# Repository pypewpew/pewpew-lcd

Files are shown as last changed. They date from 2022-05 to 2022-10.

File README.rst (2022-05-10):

PewPew LCD
**********

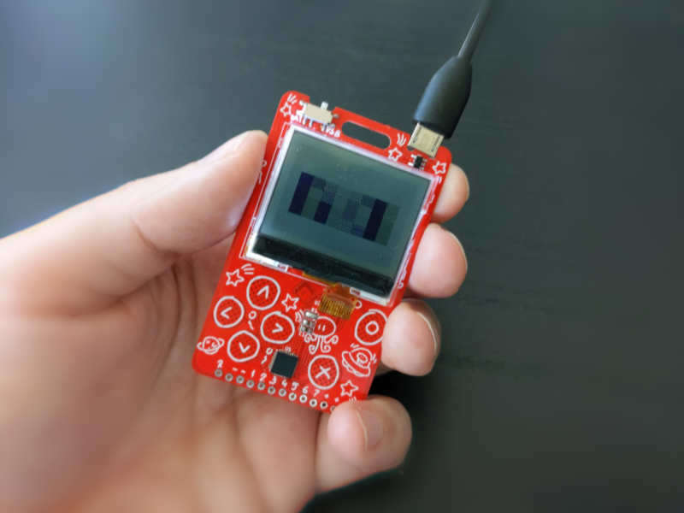
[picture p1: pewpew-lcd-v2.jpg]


PewPew LCD is a handheld gaming device designed for use in programming
workshops. Because it runs CircuitPython, you don't have to install anything on
your computer to program it: you just edit a text file on the USB drive that
appears when you connect the device.

There is a whole family of compatible PewPew devices, and PewPew LCD is just
one of them. It's distinguished by the use of a low-power monochrome LCD
display for the screen — which makes it cheap, battery-efficient, and lets you
see the error messages from your code on the screen,  without having to use any
special programs to connect to the serial console.

More information about the PewPew family is available at: https://pewpew.rtfd.io

Hardware
========

In this repository you will find the schematic, the bill of materials, the
design files and the generated gerber and pnp files, for building PewPew LCD.
You can either assemble it yourself, or use a fabrication service to do it
for you.

Software
========

For the device to function properly, it has to be loaded with proper software.
To do that, you will need a CMSIS/DAP-compatible programmer to flash the
bootloader on the microcontroller, and then you will need CircuitPython
firmware for this device, which can be flashed over USB once the bootloader is
in place. It's also convenient to put a menu program for selecting the game to
play on the device as main.py.

This device uses the same bootloader as fluff_m0. Both compiled binaries and
source code for that bootloader can be obtained from: https://github.com/adafruit/uf2-samdx1/releases/

In order to flash the bootloader, the programmer needs to be connected to the
expansion port at the bottom of the device, to pins marked as "-" for GND, "1"
for SWC, "2" for SWD, and + for 3.3V. Unless the programmer provides its own
power, the USB cable also needs to be connected, and the power switch switched
to the "USB" position. The bootloader binary needs to be flashed at address 0.

Once the bootloader is in place, a UF2 file with CircuitPython can be obtained
from the https://circuitpython.org website, or compiled from source code as per
CircuitPython's building instructions. Then the file can be copied to the
device over USB. The code for the board definition is available at 
https://github.com/adafruit/circuitpython/pull/6331

Once the firmware is in place, the menu program and any other programs desired
can be simply copied onto the device over USB.

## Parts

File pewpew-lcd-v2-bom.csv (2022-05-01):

U1 | ATSAMD21E18A-MU | 1 | mcu
U2 | AP2112K-3.3TRG1 | 1 | ldo
U3 | RH-112 | 1 | display
C1,C2 | 10uF 0805 3V | 2 | capacitor
R1 | 100ohm 0805 | 1 | resistor
X1 | MK12C02 | 1 | switch

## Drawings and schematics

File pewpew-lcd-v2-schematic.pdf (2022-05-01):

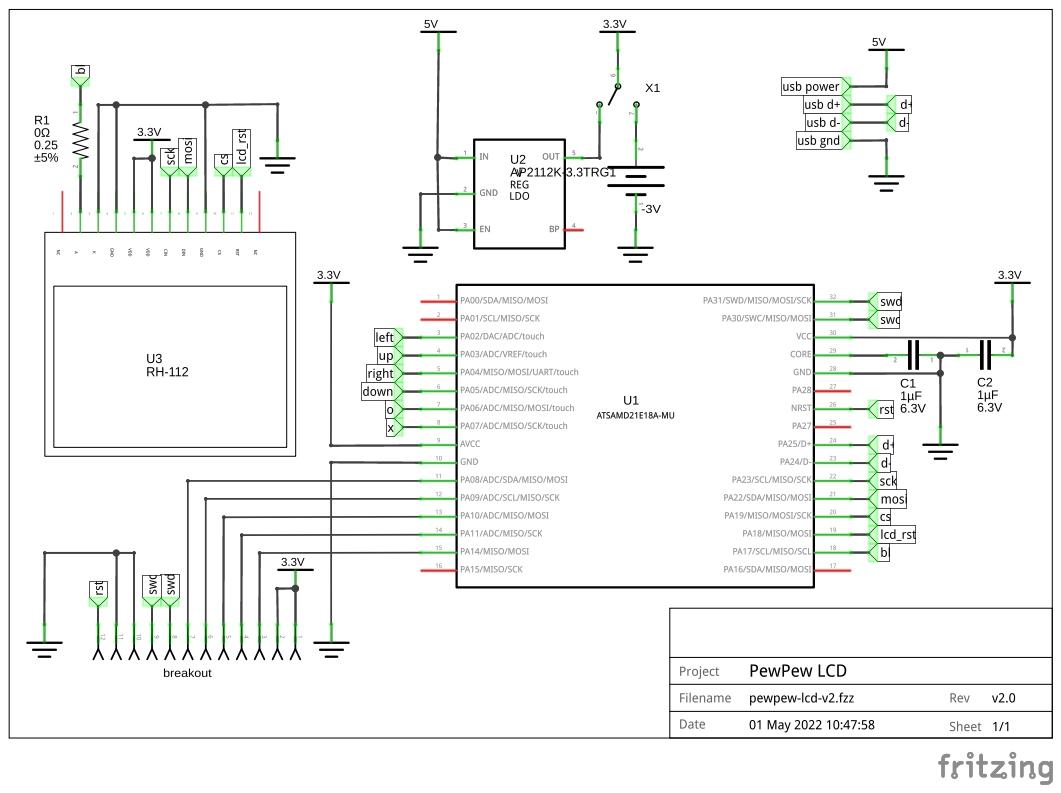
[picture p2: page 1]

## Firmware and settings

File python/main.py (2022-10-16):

import os
import pew
import supervisor
import board
import displayio
import terminalio


def _wait_keys():
    try:
        while True:
            keys = pew.keys()
            if keys:
                break
        for i in range(5):
            if not pew.keys():
                break
            pew.tick(0.0625)
        else:
            keys = pew.keys()
    except pew.GameOver:
        keys = 0
    return keys


class Menu:
    def __init__(self):
        grid = board.DISPLAY.root_group[0]
        grid = displayio.TileGrid(grid.bitmap, pixel_shader=grid.pixel_shader,
            tile_width = grid.tile_width, tile_height=grid.tile_height,
            width = 12, height = 6)
        terminal_group = displayio.Group()
        terminal_group.scale = 2
        terminal_group.append(grid)
        self.screen = displayio.Group()
        self.screen.append(terminal_group)
        bitmap = displayio.Bitmap(16, 10, 2)
        i = 0
        for byte in b'7\xf8(\x84"D*x$P$\xf0+\x10!\xf0* 7\xc0':
            for bit in range(8):
                bitmap[i] = byte & 0x80 != 0
                byte <<= 1
                i += 1
        palette = displayio.Palette(2)
        palette[0] = 0x0000
        palette[1] = 0xffff
        self.cursor = displayio.TileGrid(bitmap, pixel_shader=palette, x=0)
        self.screen.append(self.cursor)
        self.terminal = terminalio.Terminal(grid, terminalio.FONT)

    def select(self, items):
        self.terminal.write("\x1b[2J")
        for item in items[:6]:
            self.terminal.write("  %s\r\n" % item[:10])
        selected = 0
        total = min(6, len(items)) - 1
        while True:
            self.cursor.y = selected * 12 + 3
            pew.tick(0.125)
            keys = _wait_keys()
            if keys & pew.K_UP and selected > 0:
                selected -= 1
            if keys & pew.K_DOWN and selected < total:
                selected += 1
            if keys & pew.K_O:
                return items[selected]

pew.init()
menu = Menu()
board.DISPLAY.show(menu.screen)
files = [name[:-3] for name in os.listdir()
         if name.endswith('.py') and name != 'main.py']
game = menu.select(files)
supervisor.set_next_code_file("%s.py" % game, reload_on_success=True)
supervisor.reload()

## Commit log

2022-05-10 add link to board definition in CP
2022-10-16 Add version 2.1
    [pewpew-lcd-v2.1.fzz]
